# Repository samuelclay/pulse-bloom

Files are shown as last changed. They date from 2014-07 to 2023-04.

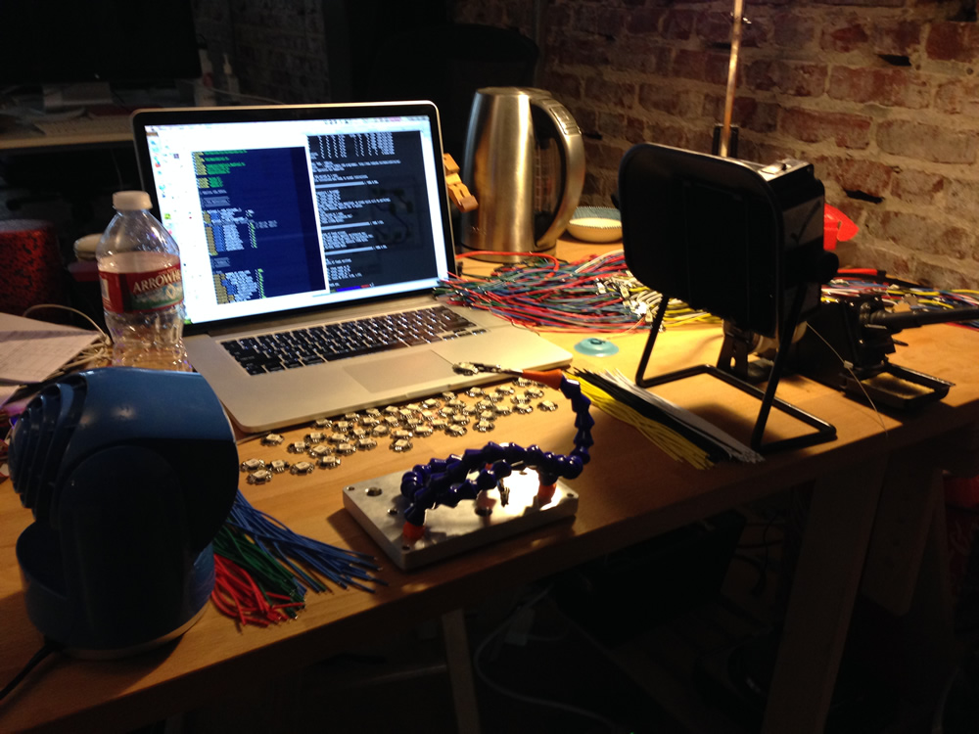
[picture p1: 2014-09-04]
blog/Pulse & Bloom - Soldering leds.jpg

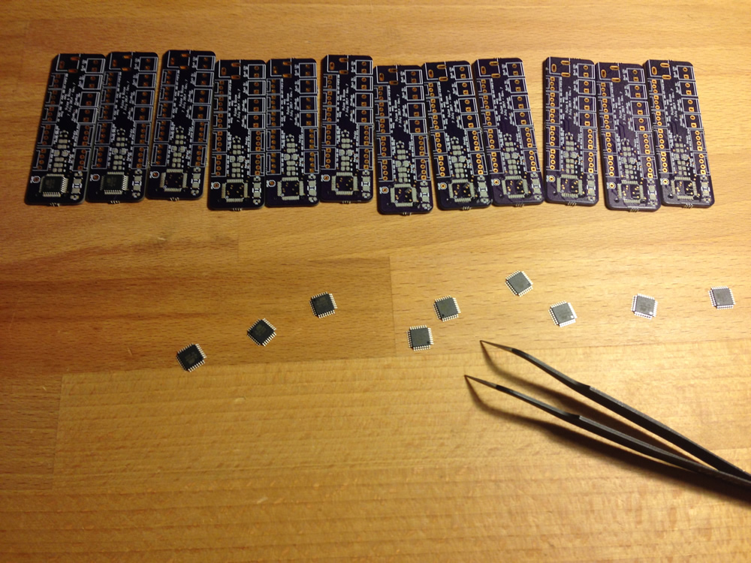
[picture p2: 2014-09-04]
blog/Pulse & Bloom - Soldering boards.jpg

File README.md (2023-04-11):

# Pulse & Bloom

Pulse & Bloom at Night

This was my second year attending Burning Man. Many use Burning Man as a week to detach from their workweek and experience a new life of intense leisure. Not me, I come to Burning Man to build.

Pulse & Bloom is a [2014 honorarium installation](http://www.burningman.com/installations/art_honor.html). The core team of 6 people — [Saba Ghole](https://twitter.com/sabarani), [Shilo Shiv Suleman](https://twitter.com/shilo1221), [Rohan Dixit](https://twitter.com/rd108), [Heather Stewart](https://www.facebook.com/heather.stewart.3388), [Luke Iseman](https://twitter.com/liseman), and [myself](http://twitter.com/samuelclay) — built 20 interactive lotus flowers made out of steel and rowlux. Each lotus flower ranges from 8 to 18 feet tall, each of which lights up with your pulse. You and another person can put your hands on a couple of Hamsa hands at the base of the lotus flower and your respective heartbeats will light up the flower.

We've gotten some great press coverage at [the BBC](http://www.bbc.com/news/in-pictures-29059374), [The Guardian](http://www.theguardian.com/artanddesign/gallery/2014/sep/06/photography-new-york-fashion-gaza-islamic-state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), [The Atlantic's Big Picture](http://www.theatlantic.com/infocus/2014/09/burning-man-2014/100802/#img07) [twice](http://www.theatlantic.com/infocus/2014/09/burning-man-2014/100802/#img22), [CBS News](http://www.cbsnews.com/pictures/burning-man-2014/9/), [NBC News](http://www.nbcnews.com/pop-culture/pop-culture-news/desert-dwellers-burning-man-festival-full-swing-n192541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), and [MSNBC](http://on.msnbc.com/1qkUN4c).

Read the entire writeup at http://www.ofbrooklyn.com/2014/09/6/building-pulse-bloom-biofeedback-burning-man-2014/.

## Setup and installation

Download the AVR GCC toolchain. You can use this homebrew-avr library to install on macOS: https://github.com/osx-cross/homebrew-avr

## Firmware

Here you can find the firmware used to program the main circuit board's ATmega328p chip, as well as designs for the laser cut cowl that sits over the pulse sensor's Si1143x IC. 

The easiest way to read the firmware is to dive into `src/pulse.cpp`. It has all of the pulse and rest states and handles the high level logic.

The state machine that runs the entire routine is determined by a couple of critical measurements. The program takes a measurement of both pulse sensors and determines whether a finger is covering either of them and whether or not that finger has an active pulse going.

    // Modes
    void determinePlayerMode();
    void determineFingerMode(int sensor1On, int sensor2On);
    void resetStem(PulsePlug *pulse);
    uint8_t adjustBpm(PulsePlug *pulse);
    
When there are no fingers on either of the pulse sensors, the program runs the rest state, which is a blue-topped lotus with a small blue snake running up and down the stem. The program is merely waiting for somebody to put their finger on a sensor.

    // State: resting
    void runResting();
    void runRestStem();
    void runRestStem(PulsePlug *pulse, int16_t currentLed);
    void clearStemLeds(PulsePlug *pulse);
    void beginPetalResting();
    bool runPetalResting();

Before a heartbeat is shown an accurate measurement of a heartbeat needs to be read. In order to determine whether a heartbeat is found and at what speed, a number of light detection measurements are taken and analyzed. I simply find the high frequency curve (the heartbeat) and the low frequency curve (the light sensors leveling out) and then use a simple peak and valley hueristic to determine the moment a heartbeat begins. This can take up to two or three seconds at first, so a bit of unwinding animation prepares you when you first put your finger on the sensor.

When a finger is detected, the stem snake lights shoot backwards up and down the lotus in prep for a heartbeat. This looks seamless as it clears the stem. This way a heartbeat doesn't interrupt the rest state.

    // State: end resting
    void beginSplittingStem();
    void runSplittingStem();
    void runSplittingStem(PulsePlug *pulse, int16_t currentLed);

When a heartbeat is detected, it is first shot up the stem. The color is determined by how many pulse sensors are being used. 1 heartbeat shows amber. 2 heartbeats show in white and light red.

    // State: stem rising
    bool runStemRising(PulsePlug *pulse, PulsePlug *shadowPulse);

Once the heartbeat reaches the top of the stem, the petals then fill with light.

    // State: petal rising
    void beginPetalRising();
    bool runPetalRising();

After a set delay, the petal slowly lose light while waiting for the next heartbeat.

    // State: petal falling
    void beginPetalFalling();
    bool runPetalFalling();

Lots of debugging messages have been left in the code and are accessible using the Serial pin on the board. Just turn on `USE_SERIAL`, which is commented out at top. Note that this increases binary code size by about 2.5K. I wrote a lot of logging.

    // Debugging
    void printHeader();
    void blink(int loops, int loopTime, bool half);
    int freeRam ();

## Contact 

I'm happy to [answer any questions on Twitter](https://twitter.com/samuelclay) or [over email](mailto:pulsebloom@ofbrooklyn.com).

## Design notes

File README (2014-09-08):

<style>
#OB-pulse-bloom ol,
#OB-pulse-bloom ul {
    margin-left: 24px;
}
#OB-pulse-bloom li {
    color: inherit;
    font-size: inherit;
    list-style-position: outside;
}
#OB-pulse-bloom ol li {
    list-style-position: outside;
    list-style-type: decimal;
}
#OB-pulse-bloom img {
    margin: 24px auto;
    border: 1px solid #303030;
    display: block;
}
#OB-pulse-bloom img.small {
    float: left;
    margin-right: 24px;
}
#OB-pulse-bloom img.no-border {
    border: none;
}
#OB-pulse-bloom pre code {
    display: block;
    overflow-y: hidden;
}
</style>

<div id="OB-pulse-bloom">

This was my second year attending Burning Man. Many use Burning Man as a week to detach from their workweek and experience a new life of intense leisure. Not me, I come to Burning Man to build.

Pulse & Bloom is a [2014 honorarium installation](http://www.burningman.com/installations/art_honor.html). The core team of 6 people — [Saba Ghole](https://twitter.com/sabarani), [Shilo Shiv Suleman](https://twitter.com/shilo1221), [Rohan Dixit](https://twitter.com/rd108), [Heather Stewart](https://www.facebook.com/heather.stewart.3388), [Luke Iseman](https://twitter.com/liseman), and [myself](http://twitter.com/samuelclay) — built 20 interactive lotus flowers made out of steel and rowlux. Each lotus flower ranges from 8 to 18 feet tall, each of which lights up with your pulse. You and another person can put your hands on a couple of Hamsa hands at the base of the lotus flower and your respective heartbeats will light up the flower.

We've gotten some great press coverage at [the BBC](http://www.bbc.com/news/in-pictures-29059374), [The Guardian](http://www.theguardian.com/artanddesign/gallery/2014/sep/06/photography-new-york-fashion-gaza-islamic-state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), [The Atlantic's Big Picture](http://www.theatlantic.com/infocus/2014/09/burning-man-2014/100802/#img07) [twice](http://www.theatlantic.com/infocus/2014/09/burning-man-2014/100802/#img22), [CBS News](http://www.cbsnews.com/pictures/burning-man-2014/9/), [NBC News](http://www.nbcnews.com/pop-culture/pop-culture-news/desert-dwellers-burning-man-festival-full-swing-n192541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), and [MSNBC](http://on.msnbc.com/1qkUN4c).

As usual, the [complete source code for Pulse & Bloom is on GitHub](https://github.com/samuelclay/pulse-bloom).

### Your heartbeat in light

Here's a video of all twenty lotus flowers in full working order.

<video src="http://static.newsblur.com.s3.amazonaws.com/ofbrooklyn/Pulse%20%26%20Bloom.mp4" autoplay loop muted width="650"></video>

Each lotus flower is blue until a person or two sits down at its base and places their hand on the pulse sensor. You can see the Hamsa hand and its embedded pulse sensor in this shot of my girlfriend Brittany and me working on keeping the electronics going.


<h6 style="margin-top: -24px;text-align: right;">Photo credit Jim Urquhart / Reuters</h6>

When a pulse is read, the lotus flower shoots the heartbeat up the stem and into the petals, where it blooms in a brilliant display of amber. When two people's hands are being measured, both of their heartbeats are shown as two distinct colors.

## How the electronics are made

There are five stages to making the electronics:

 1. [Making the custom circuit boards](#boards)
 2. [Making the custom pulse sensors](#sensors)
 3. [Driving the high current LEDs](#leds)
 4. [Writing the firmware](#firmware)
 5. [Powering the lotuses](#power)

### 1. Making the custom circuit boards

The circuit board controls all of the lighting, sensors, timing, and debugging sequences. A reliable circuit board couldn't just be an Arduino and a breadboard. I decided to use [OSH Park](http://www.oshpark.com) and [OSH Stencils](http://www.oshstencils.com) to fabricate inexpensive circuit boards. I ultimately went through seven revisions while we worked out the final design of the lotuses. This included adding additional lights, additional sensors, controls for EL wire, and better power management using an external buck converter.

This board has support for multiple high current petal LEDs driven by digital RGB pins (used for fading colors in and out using PWM) and in multiple voltages. The high current petal LEDs runs on 12V, which comes directly off the battery, the ATmega328p chip and stem LEDs run at 5V, and the pulse sensor runs at 3.3V.

To convert 12V to 5V I use [a $3 switching voltage regulator from Electrodragon](http://www.electrodragon.com/product/better-than-lm2596-dc-dc-step-down-adjustable-power-supply-module/). This requires a +/- connection for both 12V in and 5V out. To convert 5V to 3.3V I used a linear voltage regulator soldered directly on the board, since the current requirements of the pulse sensor were around 20mA. The heat dissipated was negligible compared to the rest of the circuit.

I also added terminal connections for two 5 meter LEDs that wrapped around the tall lotus stem. We attached two 5 meter LED strips around the stems because when two people put their hands on the two pulse sensors, we need an easy way to show both heartbeats without one winning out over the other. When only one person's hand in being measured, both 5 meter light strips show the same color, which makes it that much brighter for a single person.

Lastly, the two pulse sensors terminate their I2C wires directly on the board. I used two separate I2C channels instead of one to cut down on time. I could easily have put both pulse sensors on the same I2C connections, but that would've required both pull-up resistors on the SDA and SCL data lines as well as a rewrite of the timing functions for the sensor.

All of these terminations are made using 2.5mm and 3.5mm pitch screw terminals. In hindsight I would have used female JST-SM mounted connectors and ordered custom wires with JST-SM male connectors. I assumed the lowest common denomenator would be bare tinned wire, but all of the bare wires could easily have been switched over to polarized, latching connectors. This would have reduced over 90% of the field work I had to perform on boards, as their wire would fall out of the screw terminals due to not being screwed in with enough force.



The board was laid out to be as big as a pack of gum. All of the 12V traces are thickened and isolated on the right side of the board. They are rated for 3 amps although they would end up only driving 1 amp on the playa.



These boards are then stenciled with solder paste and populated with their chips and passive components.



An inexpensive hot plate is used to reflow the solder. The chip is in a TQFP package, which has a 0.5mm pitch between pins. This makes it nearly impossible to hand solder. This stencil and reflow technique works well and my yield stayed high at around 95%.



Finally, the board is ready to be populated with screw terminals.



The final board in a dust-proof enclosure.



### 2. Making the custom pulse sensors

This was both the riskiest piece of the puzzle and also the most fun to build. In order to show your heartbeat on the lotus, I need to have a clear reading of your pulse. There are a fair number of issues with most off-the-shelf heartbeat sensors, including:

 * **Cost**: While a $50 pulse sensor is nice, it's way out of our budget. We spent $6 in components to make each of our pulse sensors for a total of 40 sensors (two per lotus).
 * **Design affordance**: There were a fair number of pulse sensors that required an infrared light on one side of your finger and an infrared detector/receiver on the other. This clamping of your finger wasn't something we could get away with in the desert. We needed a sensor you could just touch and hold on one side. It needed to be a simple interface so we wouldn't have to show any instructions.
 * **Reliability**: When a sensor gets covered in dust, will it still work? Infrared light, thankfully, passes through a layer of dust and can read the changes in blood flow in your finger. Some options were entirely visual and they would have performed quite poorly out on the playa.

The first prototype I built suffered from the design affordance and reliability issues, although it worked pretty well in ideal conditions.

<video src="http://static.newsblur.com.s3.amazonaws.com/ofbrooklyn/Pulse%20%26%20Bloom%20-%20Sensor%20opamp.mp4" autoplay loop muted width="650"></video>

We ended up finding an IC by Silicon Labs called the Si1143x, which uses three LEDs — two infrared and one visible — and a small QFN-10 sized light sensor.



I built out a small PCB the size of a fingertip.



This tiny IC is a bit tricky to solder as it has no leads and the pins are extremely close together. My yield dropped to about 80%, but 4 out of every 5 pulse sensors I built worked perfectly the first time. If they failed, I would remount them on the hot plate and try wicking away any solder bridges I could find. This worked only about half the time. After that I gave up and now have a plastic cup full of broken pulse sensors.



Finally the sensor is hooked up and a tiny red light is emitted, letting people know where to put their fingers.



### 3. Driving the high current LEDs

What turned these lotuses from flowers into gems are the high current LEDs mounted in the petals at the top. There are 9 of these high current LEDs per lotus, split into groups of three, each driven by a constant current driver. 

If you were to look at one of these LEDs from a few feet away, you would immediately see spots in your eyes. They are extremely bright pinpoints of light. The fact that they are also full color and need a heatsink due to their brightness means that you won't just find these in an easy package ready for plugging in.


<h6 style="margin-top: -24px;text-align: right;">Photo credit Jim Urquhart / Reuters</h6>

Normally a single LED is powered by a single constant current driver. This driver can drive up to 1A of current at 12V. Because we were only using a single channel of color (blue) in the rest state, which is where the lotus spent most of its time, we could triple the number of LEDs driven by a single constant current driver. 

When in use the petals glow amber, which uses two channels (100% red, 50% green) but only for a moment while at peak current. So while the peak current is above what this constant current driver is rated for, it's only at peak and therefore within our tolerance.

Using a Chinese distributor, we bought these Sparkfun high current LEDs for $0.86 each instead of the full $15. However, we also bought 80 of Sparkfun's PicoBucks to use as our constant current driver. While we could have built this ourselves to save money, buying 80 of something at $15 each is still only $1.2k, while building them ourselves would only have saved a few hundred dollars.




We bought 200 high current LEDs, all of which had to have their 6 anode and cathode connections soldered.



In order to connect 9 high current LEDs to the board, we need to drive them in groups of three. Each group has 6 connections: red, green, blue anodes, and red, green, blue cathodes. The wiring diagram for this setup can get a bit rats nesty, but the end result was fairly easy to work with, as the picobuck groups didn't cross.



Finally, a shot of a complete picobuck with the wire connectors in the background.



### 4. Writing the firmware

The [complete source code for Pulse & Bloom is on GitHub](https://github.com/samuelclay/pulse-bloom). There you can find the firmware used to program the main circuit board's ATmega328p chip, as well as designs for the laser cut cowl that sits over the pulse sensor's Si1143x IC. 

The easiest way to read the firmware is to dive into `src/pulse.cpp`. It has all of the pulse and rest states and handles the high level logic.

The state machine that runs the entire routine is determined by a couple of critical measurements. The program takes a measurement of both pulse sensors and determines whether a finger is covering either of them and whether or not that finger has an active pulse going.

    // Modes
    void determinePlayerMode();
    void determineFingerMode(int sensor1On, int sensor2On);
    void resetStem(PulsePlug *pulse);
    uint8_t adjustBpm(PulsePlug *pulse);
    
When there are no fingers on either of the pulse sensors, the program runs the rest state, which is a blue-topped lotus with a small blue snake running up and down the stem. The program is merely waiting for somebody to put their finger on a sensor.

    // State: resting
    void runResting();
    void runRestStem();
    void runRestStem(PulsePlug *pulse, int16_t currentLed);
    void clearStemLeds(PulsePlug *pulse);
    void beginPetalResting();
    bool runPetalResting();

Before a heartbeat is shown an accurate measurement of a heartbeat needs to be read. In order to determine whether a heartbeat is found and at what speed, a number of light detection measurements are taken and analyzed. I simply find the high frequency curve (the heartbeat) and the low frequency curve (the light sensors leveling out) and then use a simple peak and valley hueristic to determine the moment a heartbeat begins. This can take up to two or three seconds at first, so a bit of unwinding animation prepares you when you first put your finger on the sensor.

When a finger is detected, the stem snake lights shoot backwards up and down the lotus in prep for a heartbeat. This looks seamless as it clears the stem. This way a heartbeat doesn't interrupt the rest state.

    // State: end resting
    void beginSplittingStem();
    void runSplittingStem();
    void runSplittingStem(PulsePlug *pulse, int16_t currentLed);

When a heartbeat is detected, it is first shot up the stem. The color is determined by how many pulse sensors are being used. 1 heartbeat shows amber. 2 heartbeats show in white and light red.

    // State: stem rising
    bool runStemRising(PulsePlug *pulse, PulsePlug *shadowPulse);

Once the heartbeat reaches the top of the stem, the petals then fill with light.

    // State: petal rising
    void beginPetalRising();
    bool runPetalRising();

After a set delay, the petal slowly lose light while waiting for the next heartbeat.

    // State: petal falling
    void beginPetalFalling();
    bool runPetalFalling();

Lots of debugging messages have been left in the code and are accessible using the Serial pin on the board. Just turn on `USE_SERIAL`, which is commented out at top. Note that this increases binary code size by about 2.5K. I wrote a lot of logging.

    // Debugging
    void printHeader();
    void blink(int loops, int loopTime, bool half);
    int freeRam ();

### 5. Powering the lotuses

While much of what I built above came out of knowledge I already had, learning how to power this large of an installation off just a battery was all new to me. I'm used to microelectronics that run off a coin cell or AA batteries.

#### Measuring current and power usage

First, in order to figure out how big of a battery we needed, we had to measure how much power we were taking. I hooked up an ammeter in series with a single lotus to measure the current draw. In rest state, a single lotus drew 0.75A at 12V. In the active pulsing heartbeat state, a single lotus drew 1.5A at 12V. Since a lotus spends 95% of its time at rest, we rounded the average current consumption to 1A.

Twenty lotuses at 1A at 12V meant we needed 240Ah to sustain a 12 hour night. A car battery was recommended, but car batteries can only discharge down to 80% without irreparable harm. However, a marine deep-cycle battery can go down to 20% without harm. 



This 150 lb. battery has enough capacity, although we ended up adding a couple 6V batteries in series (to boost them to 12V) and then running them in parallel to offset some of the load.

#### Dealing with the voltage drop

A big issue we ran into was the voltage drop across the power lines. We placed the batteries on the edge of the installation, which meant some of the lotuses had 20 meters of wire between them and the battery. The voltage drop per 10 meter section is nearly 2V, which means that the voltage reaching the further lotuses was down to 7.5V. 

The high current LEDs were not able to be smoothly driven at this low of a voltage, causing them to flicker. We determined that a voltage drop was responsible for the flickering, which got worse the further the lotus sat from the batteries. But when we discovered this the wires had already been trenched 6 inches beneath the playa. A day of work lost, but we sucked it up and ripped out all of the ground wiring to accommodate the battery which had to be moved into the center of the installation.

At the end of each night we had to bike out with a trike and carry all 300 lbs. of batteries back to camp, where they were hooked up to a 1 kW solar array, where they were charged at 48A over 6 hours.

## Prototyping the lotuses

Back at American Steel in Oakland, the lotus stems, bases, and petals were ready to be hooked up. These twenty lotus stems were bent by Heather. They range from 6ft to 16ft in length and each weighs 50 lbs.



Such a heavy stem needs a larger base and heavy anchors to stay upright in the wind.



We placed the lily pad over the base to cover it up and then added all of the electronics. Lights, sensors, and circuit boards all had to be mounted.

This is a photo of our first complete lotus flower. Just compare its sheer size to Shilo.



Once we were confident that one lotus would successfully light we left the other 19 lotuses packed away for assembly on the playa.

## A dusty scene

We drove out in the biggest rental car I could get my hands on. Our minivan is full of electronics, bicycles, tents, costumes, coolers full of fruit and veggies, dry snacks, and water.



Since we were early arrival, they give you these red bracelets. They say *Work hard, don't do stupid shit*.



The boards would accumulate dust on them everyday. Our plastic enclosures turned out to be too big for the holes we made in the platform. So we ended up using ziploc bags. These baggies stayed attached, but the only reason they didn't cause any issues is that the boards worked just fine in the dust, as you can see here. 

If dust was a real problem for the boards, then I would have spent a whole lot more time making a tight fitting enclosure and a hole for it that protects it both from the elements and from people.



The playa gets covered in dust storms regularly throughout the week. A particularly nasty dust storm is pictured here, eating our poor lotus flowers alive.



Although during the day when its not dust storming the lotuses offer a cozy respite from the heat of the playa. 


<h6 style="margin-top: -24px;text-align: right;">Photo credit Jim Urquhart / Reuters</h6>

The entire process lasted 4 months with 2.5 months of nearly full-time work on my part. I'm thrilled that I get to open-source both the process and the firmware. I hope others who build art installations can use some of my lessons learned here. I'm happy to [answer any questions on Twitter](https://twitter.com/samuelclay).

See you next year on the playa!

</div>

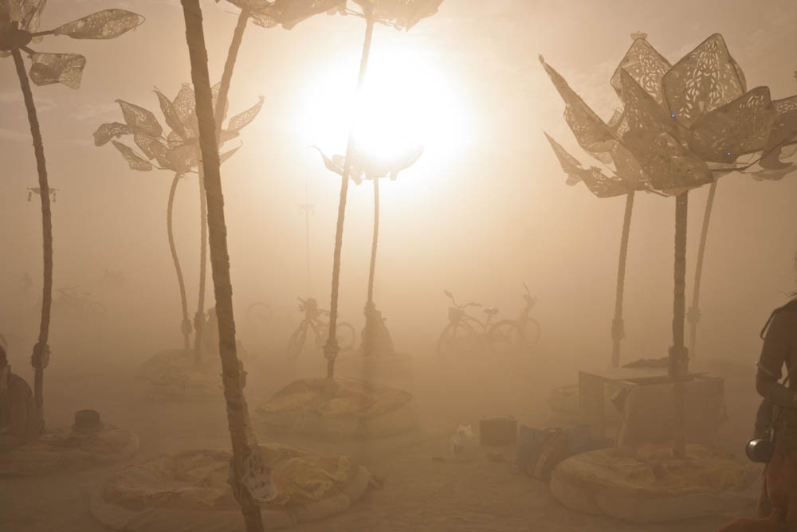
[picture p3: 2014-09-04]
blog/Pulse & Bloom - Dust.jpg

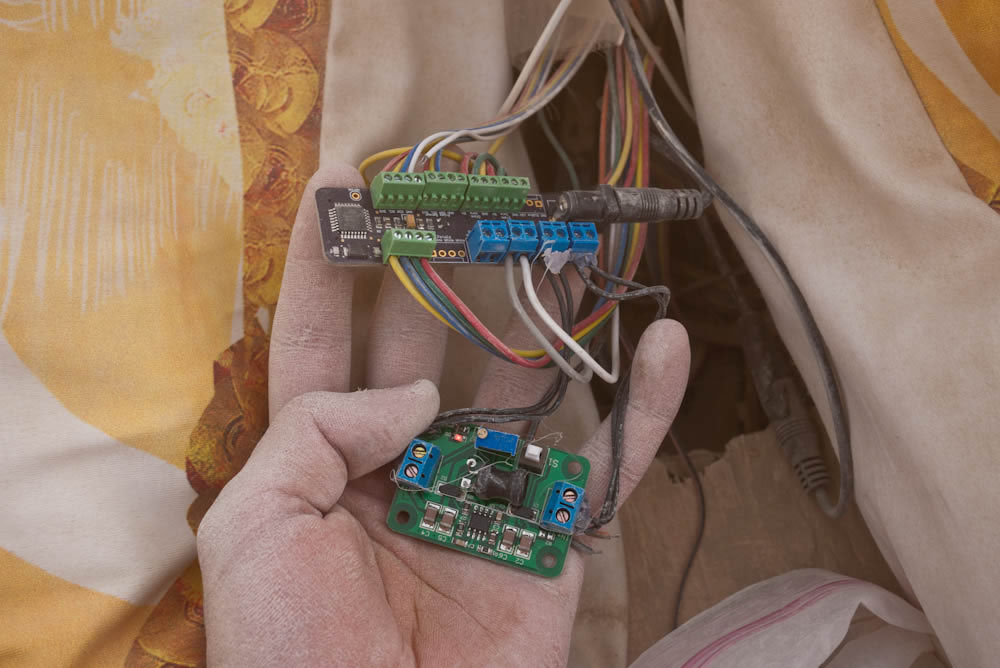
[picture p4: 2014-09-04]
blog/Pulse & Bloom - Dusty Board.jpg

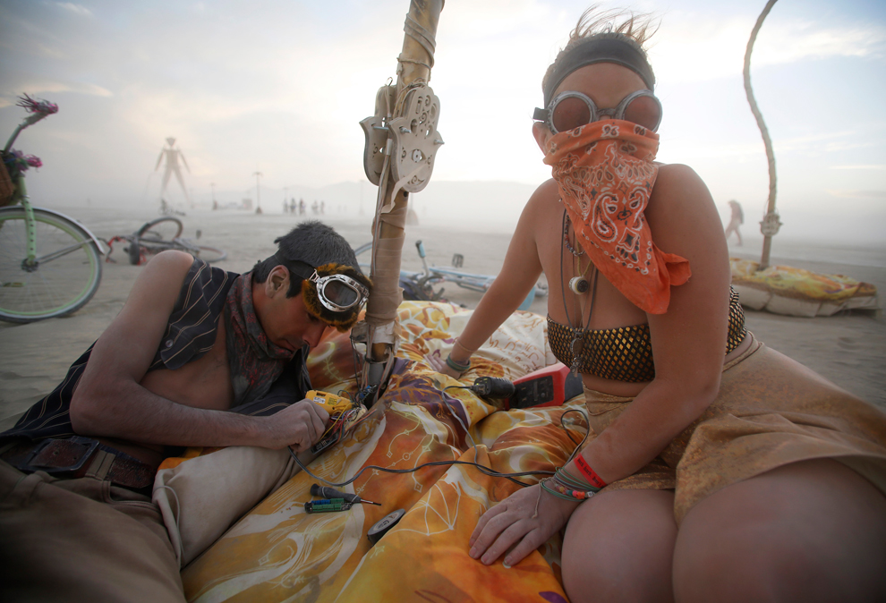
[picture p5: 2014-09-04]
blog/Pulse & Bloom - Glue Gun.jpg

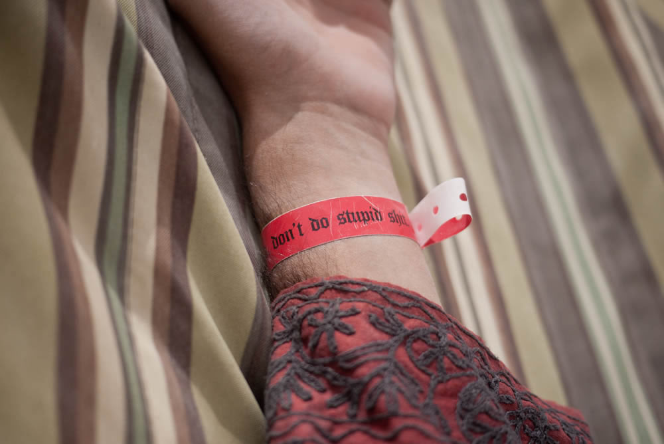
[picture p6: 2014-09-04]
blog/Pulse & Bloom - Bracelet.jpg

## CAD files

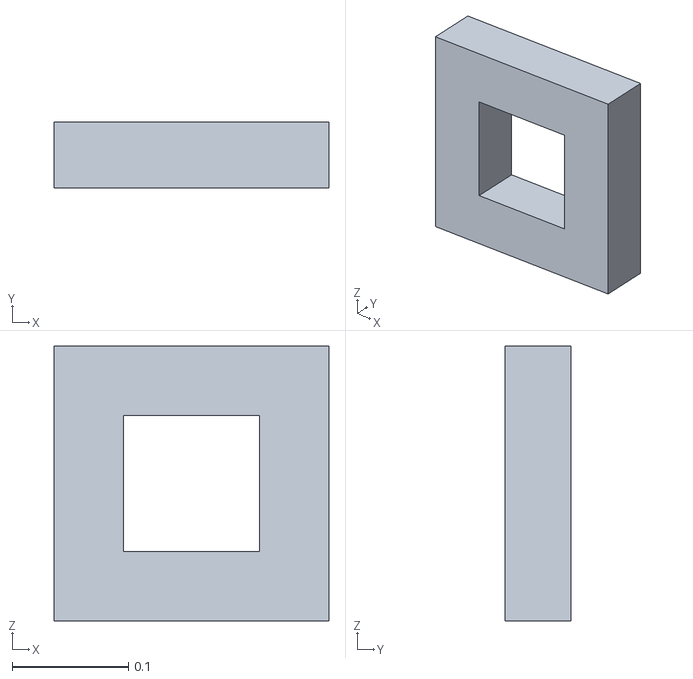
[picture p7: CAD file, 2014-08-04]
cowl/Pulse Sensor Cowl.obj
0.237 x 0.057 x 0.237

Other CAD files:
cowl/Pulse Sensor Cowl.skp
cowl/Pulse Sensor Cowl~.skp

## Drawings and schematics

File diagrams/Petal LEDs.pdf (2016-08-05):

## Petal LEDs.graffle

## Board

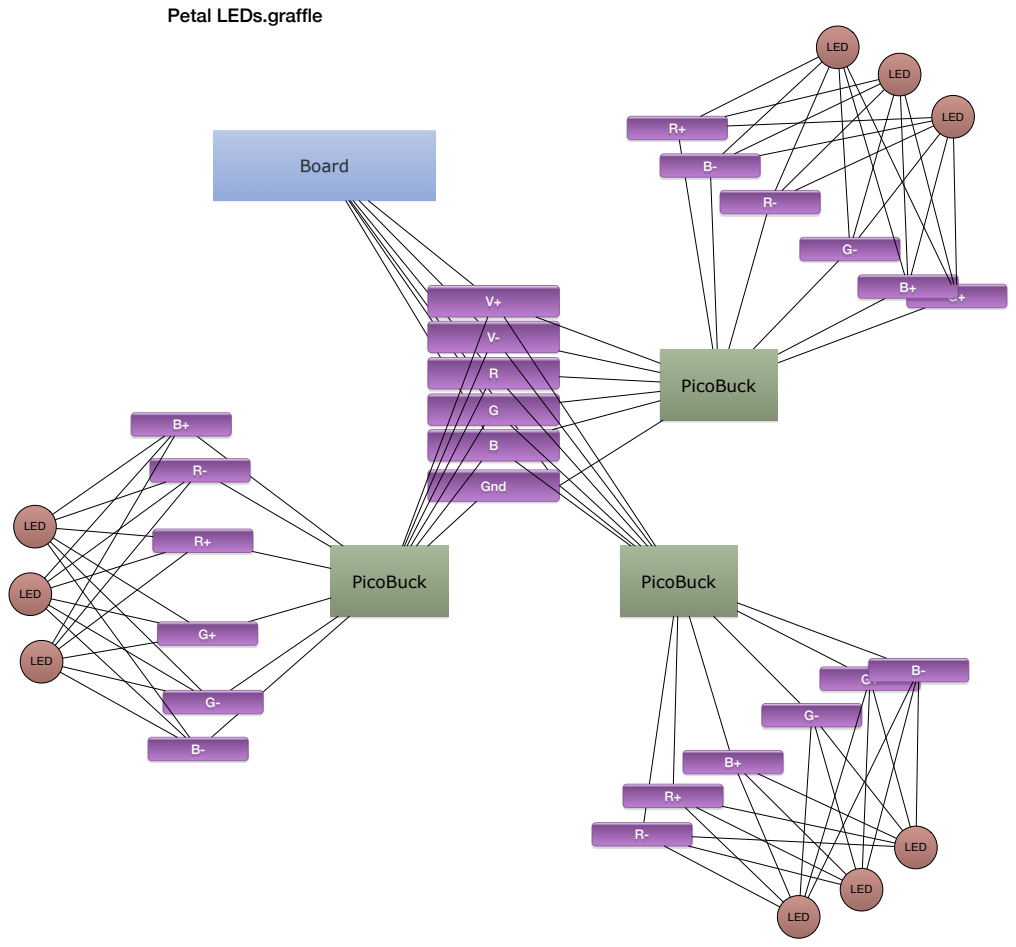
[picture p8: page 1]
LED; Gnd; PicoBuck

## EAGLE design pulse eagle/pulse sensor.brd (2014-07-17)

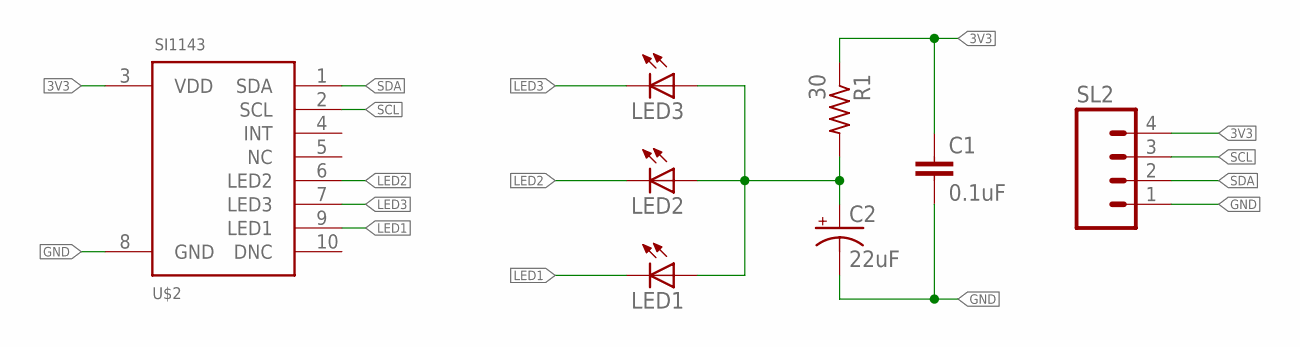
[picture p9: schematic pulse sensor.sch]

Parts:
C1: 0.1uF; 0402-CAP
C2: 22uF; EIA3216
LED1, LED2, LED3: LED1206; LED-1206
R1: 30; R0402
SL2: M04SMD; 1X04-SMD
U$2: SI1143

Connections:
3V3: C1.1, R1.1, SL2.4, U$2.3 (VDD)
GND: C1.2, C2.C (-), SL2.1, U$2.8 (GND)
LED1: LED1.C, U$2.9 (LED1)
LED2: LED2.C, U$2.6 (LED2)
LED3: LED3.C, U$2.7 (LED3)
unnamed: C2.A (+), LED1.A, LED2.A, LED3.A, R1.2
SCL: SL2.3, U$2.2 (SCL)
SDA: SL2.2, U$2.1 (SDA)

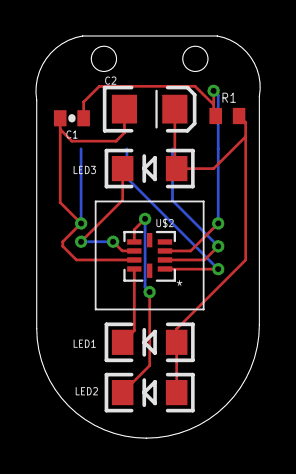
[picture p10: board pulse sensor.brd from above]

Board: 2 copper layers, 12.5 x 22.3 mm, 8 parts (1 on the bottom side), 8 nets.

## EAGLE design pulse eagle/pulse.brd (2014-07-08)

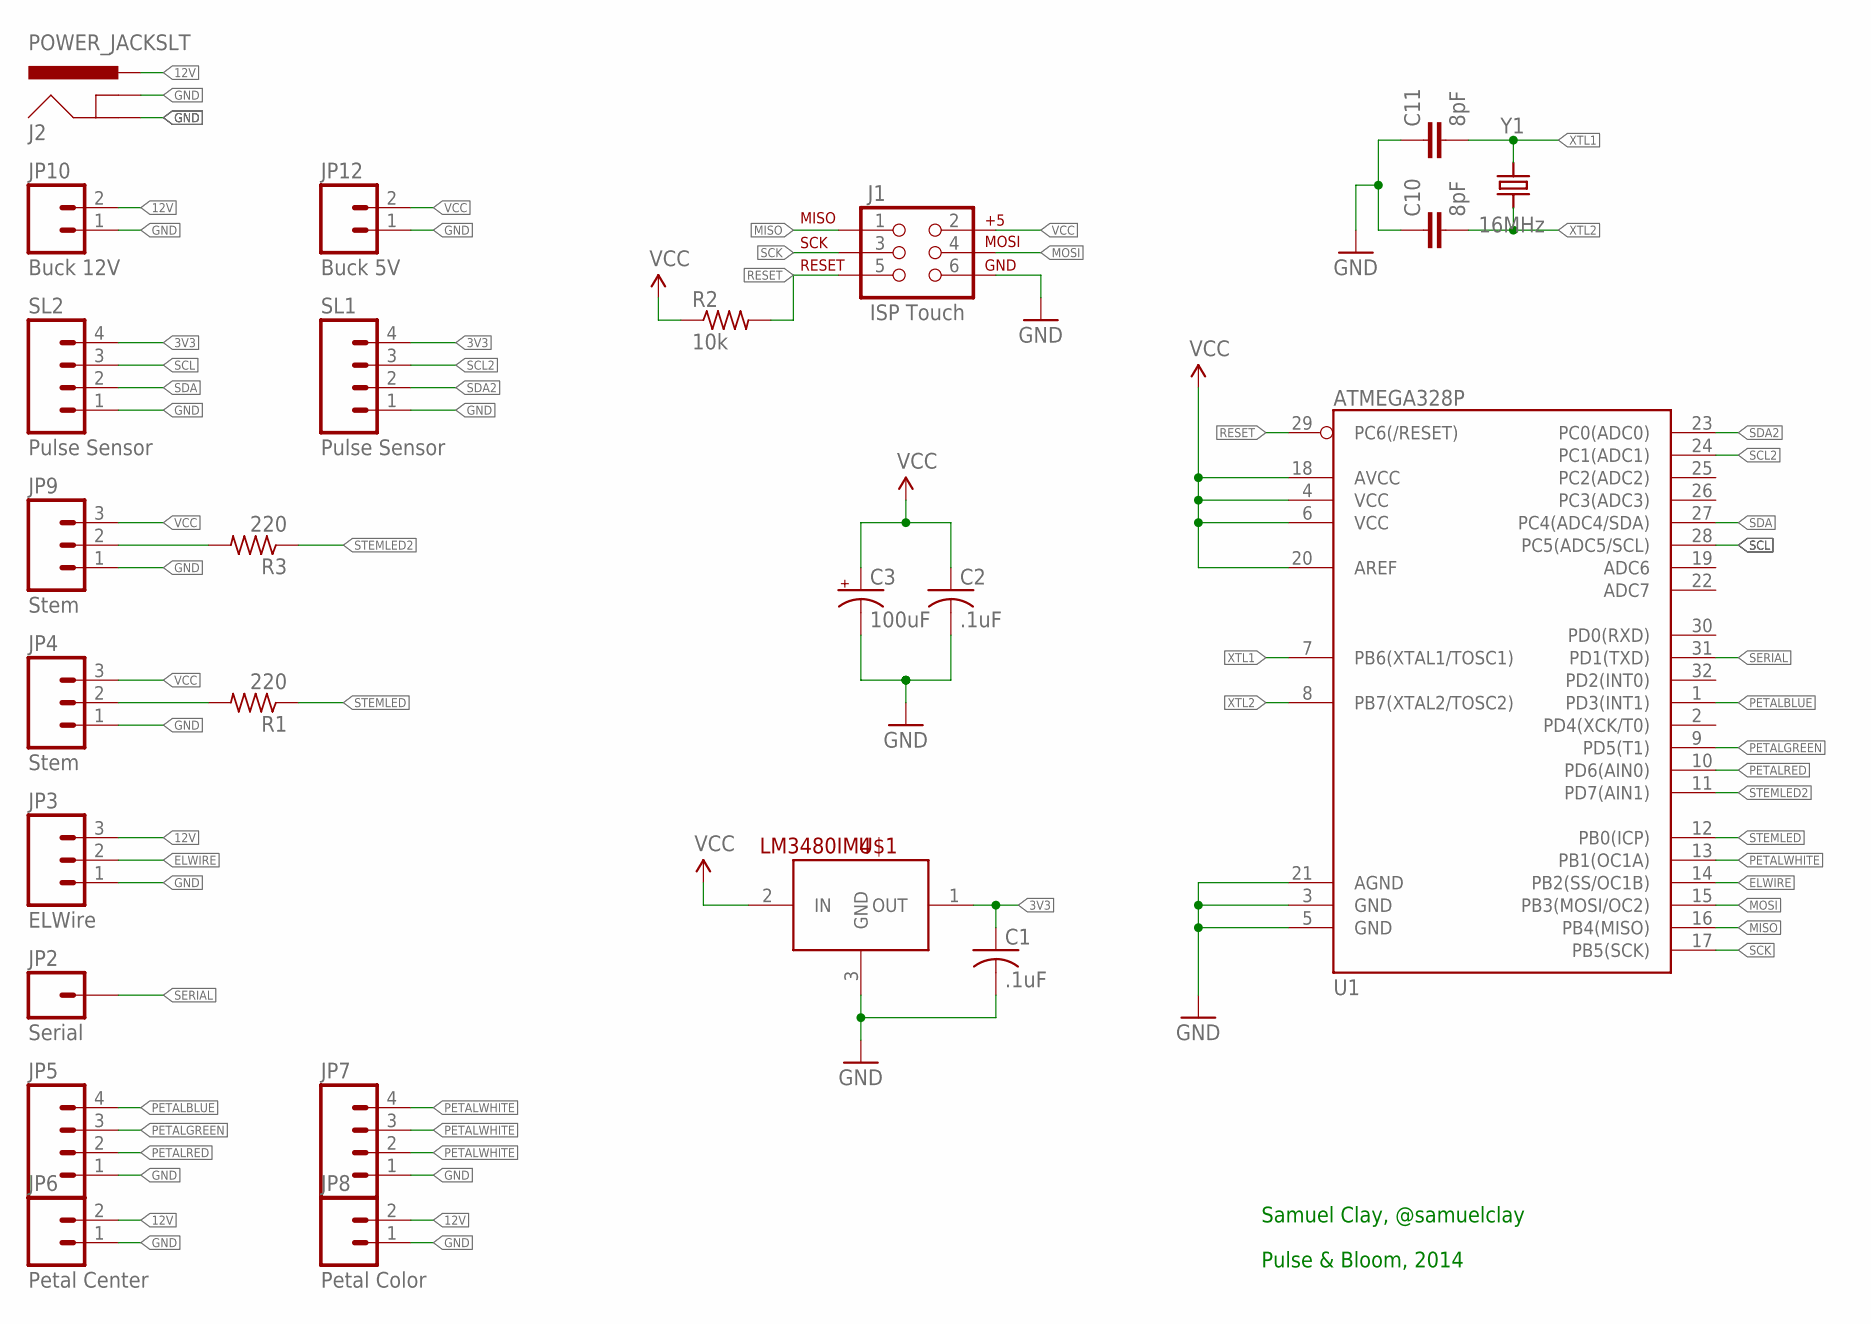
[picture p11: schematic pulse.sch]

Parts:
C1, C2: .1uF; C0805
C3: 100uF; EIA3216
C10, C11: 8pF; 0805
J1: ISP Touch; AVX_9188_6-WAY_MATING_GUIDE
J2: POWER_JACKSLT; POWER_JACK_SLOT
JP2: Serial; 1X01
JP3: ELWire; MOLEX-1X3_LOCK
JP4, JP9: Stem; MOLEX-1X3_LOCK
JP5: M04POLAR_LOCK; MOLEX-1X4_LOCK
JP6: Petal Center; SCREWTERMINAL-3.5MM-2_LOCK
JP7: M04POLAR; MOLEX-1X4
JP8: Petal Color; SCREWTERMINAL-3.5MM-2_LOCK
JP10: Buck 12V; SCREWTERMINAL-3.5MM-2_LOCK
JP12: Buck 5V; SCREWTERMINAL-3.5MM-2_LOCK
R1, R3: 220; R0805
R2: 10k; R0805
SL1, SL2: Pulse Sensor; MOLEX-1X4_LOCK
U1: ATMEGA328P; TQFP32-08
U$1: LM3480IM4; SOT23-3
Y1: 16MHz; NX5032GA

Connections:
3V3: C1.1, SL1.4, SL2.4, U$1.1 (OUT)
12V: J2.PWR, JP3.3, JP6.2, JP8.2, JP10.2
ELWIRE: JP3.2, U1.14 (PB2(SS/OC1B))
GND: C1.2, C2.2, C3.C (-), C10.1, C11.1, J1.6, J2.GND@1 (GNDBREAK), J2.GND@2 (GND), JP3.1, JP4.1, JP5.1, JP6.1, JP7.1, JP8.1, JP9.1, JP10.1, JP12.1, SL1.1, SL2.1, U1.3 (GND), U1.5 (GND), U1.21 (AGND), U$1.3 (GND)
MISO: J1.1, U1.16 (PB4(MISO))
MOSI: J1.4, U1.15 (PB3(MOSI/OC2))
unnamed: JP9.2, R3.2
unnamed: JP4.2, R1.2
PETALBLUE: JP5.4, U1.1 (PD3(INT1))
PETALGREEN: JP5.3, U1.9 (PD5(T1))
PETALRED: JP5.2, U1.10 (PD6(AIN0))
PETALWHITE: JP7.2, JP7.3, JP7.4, U1.13 (PB1(OC1A))
RESET: J1.5, R2.2, U1.29 (PC6(/RESET))
SCK: J1.3, U1.17 (PB5(SCK))
SCL: SL2.3, U1.28 (PC5(ADC5/SCL))
SCL2: SL1.3, U1.24 (PC1(ADC1))
SDA: SL2.2, U1.27 (PC4(ADC4/SDA))
SDA2: SL1.2, U1.23 (PC0(ADC0))
SERIAL: JP2.1, U1.31 (PD1(TXD))
STEMLED: R1.1, U1.12 (PB0(ICP))
STEMLED2: R3.1, U1.11 (PD7(AIN1))
VCC: C2.1, C3.A (+), J1.2, JP4.3, JP9.3, JP12.2, R2.1, U1.4 (VCC), U1.6 (VCC), U1.18 (AVCC), U1.20 (AREF), U$1.2 (IN)
XTL1: C11.2, U1.7 (PB6(XTAL1/TOSC1)), Y1.P$2 (2)
XTL2: C10.2, U1.8 (PB7(XTAL2/TOSC2)), Y1.P$1 (1)

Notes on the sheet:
Samuel Clay, @samuelclay
Pulse & Bloom, 2014

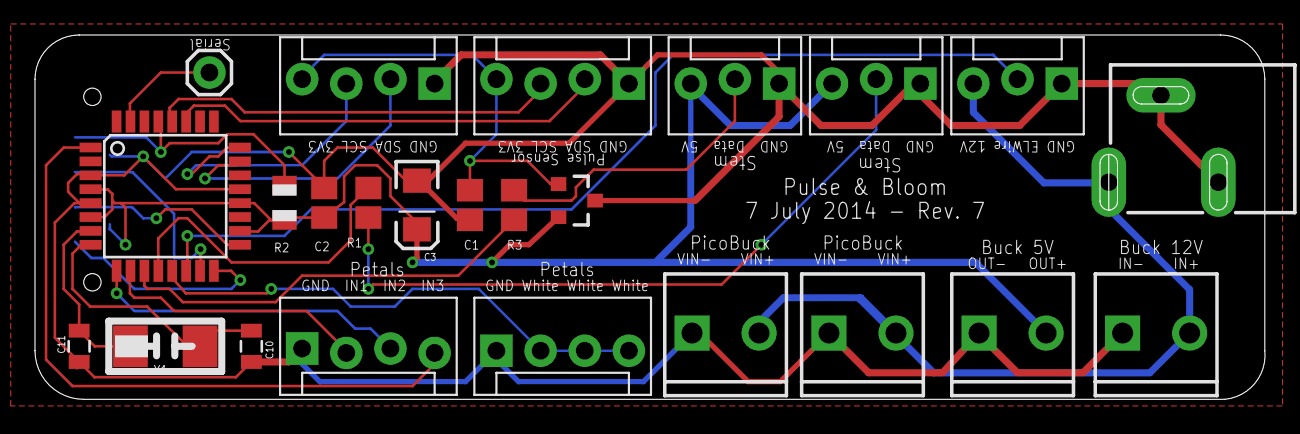
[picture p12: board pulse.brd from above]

Board: 2 copper layers, 70.8 x 21.0 mm, 25 parts (1 on the bottom side), 24 nets.

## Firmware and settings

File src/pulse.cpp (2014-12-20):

// Pulse & Bloom - Pulse Sensor and Lighting
// 2014 - Samuel Clay, samuel@ofbrooklyn.com

#include <avr/io.h>
#include <util/delay.h>     /* for _delay_ms() */
#include <stdio.h>
#include <string.h>
#include <inttypes.h>
#include <wdt.h>
#include <WString.h>
#if defined (__AVR_ATtiny84__)
#include <tiny/wiring.h>
#include <SoftwareSerial/SoftwareSerial.h>
#else
#include <HardwareSerial.h>
#endif
#include <neopixel/Adafruit_NeoPixel.h>
#include <si1143/si1143.h>
#include <QuadraticEase.h>

#include "pulse.h"
#include "sensor.h"
#include "smooth.h"

// #define USE_SERIAL

// ===================
// = Pin Definitions =
// ===================

#if defined (__AVR_ATtiny84__)
const uint8_t stemLedPin          = PB2;
const uint8_t serialPin           = 7;
#elif defined (__AVR_ATmega328P__)
// See si1143.h:digiPin for sensor pins
const uint8_t sensorAPin          = 0;  // SCL=18, SDA=19
const uint8_t sensorBPin          = 14; // SCL=A0, SDA=A1
const uint8_t stemALedPin         = 8;
const uint8_t stemBLedPin         = 7;
const uint8_t petalRedPin         = 3;
const uint8_t petalGreenPin       = 6;
const uint8_t petalBluePin        = 5;
const uint8_t petalWhitePin       = 9;
#endif

// ===========
// = Globals =
// ===========

// Stem
const int NUMBER_OF_STEM_LEDS     = 300;
const int REST_PULSE_WIDTH        = 8;
const int8_t STEMA_PULSE_WIDTH    = 16;
const int8_t STEMB_PULSE_WIDTH    = 16;
volatile int16_t stripACurrentLed = 0;
volatile int16_t stripBCurrentLed = 0;
volatile int16_t splitPivotPoint  = 0;
unsigned long beginSplitTime      = 0;
unsigned long endSplitTime        = 0;
const int STEM_SPLIT_MS           = 800;
const double STEM_DURATION_PCT    = 0.65;

QuadraticEase splitEase;

// Petals
unsigned long beginLedRiseTime    = 0;
unsigned long endLedRiseTime      = 0;
unsigned long beginLedFallTime    = 0;
unsigned long endLedFallTime      = 0;
unsigned long beginLedRestTime    = 0;
unsigned long endLedRestTime      = 0;
uint8_t ledBrightness             = 0;
uint8_t lastBpm                   = 75;
const int16_t PETAL_DECAY_MS      = 850;
const int16_t PETAL_DELAY_MS      = 60;

// Pulses
unsigned long lastPulseATime      = 0;
unsigned long lastPulseBTime      = 0;
unsigned long nextPulseATime      = 0;
unsigned long nextPulseBTime      = 0;
unsigned int bpmPulseA            = lastBpm;
unsigned int bpmPulseB            = lastBpm;
unsigned long lastSensorActiveA   = 0;
unsigned long lastSensorActiveB   = 0;
unsigned long lastFingerSeenA     = 0;
unsigned long lastFingerSeenB     = 0;
const int SENSOR_DECAY_MS         = 60000;
const int FINGERLESS_DECAY_MS     = 1500;
const double SHOW_HEARTBEAT_PCT   = 0.35;

// Pulse sensor
PortI2C myBus(sensorAPin);
PulsePlug pulseA(myBus); 
PortI2C myBus2(sensorBPin);
PulsePlug pulseB(myBus2); 

// States
typedef enum
{
    STATE_RESTING       = 0,
    STATE_AWAKE         = 1,
    STATE_STEM_RISING   = 2,
    STATE_STEM_FALLING  = 3,
    STATE_PETAL_RISING  = 4,
    STATE_PETAL_FALLING = 5,
    STATE_PETAL_LANDING = 6
} state_app_t;
state_app_t app1State;
state_app_t app2State;
state_app_t restState;
state_app_t petalState;

typedef enum
{
    MODE_NONE     = 0,
    MODE_SINGLE_A = 1,
    MODE_SINGLE_B = 2,
    MODE_DOUBLE   = 3
} player_mode_t;
player_mode_t playerMode;
player_mode_t fingerMode;

// Serial
#if defined (__AVR_ATtiny84__)
SoftwareSerial Serial(0, serialPin); // RX, TX
#endif

// Debugging
long debuggingTimer   = 0;
long debuggingSeconds = 0;

// ========
// = Init =
// ========

void setup(){
    analogReference(EXTERNAL);
    pinMode(petalRedPin, OUTPUT);
    pinMode(petalGreenPin, OUTPUT);
    pinMode(petalBluePin, OUTPUT);
    pinMode(petalWhitePin, OUTPUT);
    
    analogWrite(petalRedPin, 0);
    analogWrite(petalGreenPin, 0);
    analogWrite(petalBluePin, 0);
    analogWrite(petalWhitePin, 0);
    
    app1State  = STATE_RESTING;
    app2State  = STATE_RESTING;
    petalState = STATE_RESTING;
    restState  = STATE_RESTING;
    playerMode = MODE_NONE;
    fingerMode = MODE_NONE;
    
    delay(50);
#ifdef USE_SERIAL
    Serial.begin(115200);
    Serial.flush();
    
    Serial.print(F(" ---> Free RAM: "));
    Serial.println(freeRam());
#endif
    printHeader();
    
    pinMode(stemALedPin, OUTPUT);
    digitalWrite(stemALedPin, LOW);
    pinMode(stemBLedPin, OUTPUT);
    digitalWrite(stemBLedPin, LOW);
    clearStemLeds(&pulseA);
    clearStemLeds(&pulseB);
    pulseA.role = ROLE_PRIMARY;
    pulseB.role = ROLE_SECONDARY;
    setupPulseSensor(&pulseA);
    setupPulseSensor(&pulseB);

    for (int i=0; i < 255; i++) {
        analogWrite(petalRedPin, i);
        delay(1);
    }
    for (int i=255; i > 0; i--) {
        analogWrite(petalRedPin, i);
        delay(1);
    }
    for (int i=0; i < 255; i++) {
        analogWrite(petalGreenPin, i);
        delay(1);
    }
    for (int i=255; i > 0; i--) {
        analogWrite(petalGreenPin, i);
        delay(1);
    }
    for (int i=0; i < 255; i++) {
        analogWrite(petalBluePin, i);
        delay(1);
    }
    for (int i=255; i > 0; i--) {
        analogWrite(petalBluePin, i);
        delay(1);
    }


    analogWrite(petalRedPin, 0);
    analogWrite(petalGreenPin, 0);
    analogWrite(petalBluePin, 255);
    analogWrite(petalWhitePin, 0);
    
    // blink(3, 25, true);
}

void loop() {
    bool heartbeat1 = lastPulseATime && nextPulseATime < millis();
    bool heartbeat2 = lastPulseBTime && nextPulseBTime < millis();
    int sensor1On = readPulseSensor(&pulseA);
    int sensor2On = readPulseSensor(&pulseB);
    PulsePlug *pulse1 = &pulseA;
    PulsePlug *pulse2 = &pulseB;
    
#ifdef USE_SERIAL
    if (true && (heartbeat1 || heartbeat2 || 
                 sensor1On >= 0 || sensor2On >= 0 || 
                 app1State || app2State)) {
        Serial.print(F(" ---> ["));
        Serial.print(millis());
        Serial.print(F("] mode: "));        Serial.print(playerMode);
        Serial.print(F(" heartbeat: "));    Serial.print(heartbeat1);
        Serial.print(F("/"));               Serial.print(heartbeat2);
        Serial.print(F(" sensorOn: "));     Serial.print(sensor1On);
        Serial.print(F("/"));               Serial.print(sensor2On);
        Serial.print(F(" appState: "));     Serial.print(app1State);
        Serial.print(F("/"));               Serial.print(app2State);
        Serial.print(F(" restState: "));    Serial.print(restState);
        Serial.print(F("/"));               Serial.print(app2State);
        Serial.print(F(" petalState: "));   Serial.print(petalState);
        Serial.println();
    }
#endif    
    
    // Found fingers, now in transitory state, just skip everything until done
    if (restState == STATE_STEM_RISING) {
        runSplittingStem();
        return;
    }
    if (playerMode == MODE_NONE) {
        lastPulseATime = 0;
        lastPulseBTime = 0;
        nextPulseATime = 0;
        nextPulseBTime = 0;
        app1State = STATE_RESTING;
        app2State = STATE_RESTING;
        if (fingerMode == MODE_NONE) {
            runResting();
            if (petalState != STATE_RESTING) {
                petalState = STATE_PETAL_LANDING;
            }
        }
    }
    
    // Check for real heartbeat, adjust fake heartbeat
    if (sensor1On > 0) {
        bpmPulseA = adjustBpm(pulse1);
        float progress = 1.0;
        if (lastPulseATime) {
            progress = ((float)(millis()-lastPulseATime))/
                       ((float)(nextPulseATime-lastPulseATime));
        }
        lastSensorActiveA = millis();
        if (progress > SHOW_HEARTBEAT_PCT) {
            // If half-way to next heartbeat, immediately show heartbeat
            heartbeat1 = true;
        } else {
            // If not half-way to next heartbeat, push out next heartbeat to align
            // with this real heartbeat.
            Serial.print(" ---> Saw heartbeatA, delaying: ");
            Serial.println(progress);

            nextPulseATime = millis() + 60000.0/bpmPulseA;
        }
    }
    if (sensor2On > 0) {
        float progress = 1.0;
        if (lastPulseBTime) {
            progress = ((float)(millis()-lastPulseBTime))/((float)(nextPulseBTime-lastPulseBTime));
        }
        lastSensorActiveB = millis();
#ifdef USE_SERIAL
        Serial.print(" ---> Progress: ");
        Serial.print(progress);
        Serial.print(" lastbpm: ");
        Serial.print(lastBpm);
        Serial.print(" bpm: ");
        Serial.print(pulse2->latestBpm);
        Serial.print(" newbpm: ");
        Serial.println(adjustBpm(pulse2));
#endif
        bpmPulseB = adjustBpm(pulse2);
        if (progress > SHOW_HEARTBEAT_PCT) {
            heartbeat2 = true;
        } else {
            Serial.print(" ---> Saw heartbeatB, delaying: ");
            Serial.println(progress);
            nextPulseBTime = millis() + 60000.0/bpmPulseB;
        }
    }

    // If finger's gone, ensure no faked heartbeat
    if (sensor1On < 0) {
        heartbeat1 = false;
        lastPulseATime = 0;
        nextPulseATime = 0;
    } else {
        lastFingerSeenA = millis();
    }
    if (sensor2On < 0) {
        heartbeat2 = false;
        lastPulseBTime = 0;
        nextPulseBTime = 0;
    } else {
        lastFingerSeenB = millis();
    }
    
    // Check for faked/real heartbeat, turn on stem
    if (heartbeat1) {
        lastPulseATime = millis();
        nextPulseATime = lastPulseATime + 60000.0/bpmPulseA;
        if (app1State == STATE_STEM_RISING && petalState != STATE_PETAL_RISING) {
            // If stem is already rising and is about to be cut off, pulse petals
            petalState = STATE_PETAL_RISING;
            beginPetalRising();
        }
        app1State = STATE_STEM_RISING;
        resetStem(pulse1);
        // Use both stems if in single player mode
        if (playerMode == MODE_SINGLE_A) resetStem(pulse2);
    } else if (app1State == STATE_STEM_RISING ||
               (playerMode == MODE_SINGLE_B && app2State == STATE_STEM_RISING)) {
        // Run stem, move to petal when complete
        bool stem1Done = runStemRising(pulse1, playerMode == MODE_SINGLE_B ? pulse2 : pulse1);
        if (stem1Done && app1State == STATE_STEM_RISING) {
            app1State = STATE_RESTING;
            resetStem(pulse1);
            if (playerMode == MODE_SINGLE_A) resetStem(pulse2);
            if (petalState != STATE_PETAL_RISING) {
                petalState = STATE_PETAL_RISING;
                beginPetalRising();
            }
        }
    } 
    
    if (heartbeat2) {
        lastPulseBTime = millis();
        nextPulseBTime = lastPulseBTime + 60000.0/bpmPulseB;
        if (app2State == STATE_STEM_RISING && petalState != STATE_PETAL_RISING) {
            // If stem is already rising and is about to be cut off, pulse petals
            petalState = STATE_PETAL_RISING;
            beginPetalRising();
        }
        app2State = STATE_STEM_RISING;
        resetStem(pulse2);
        if (playerMode == MODE_SINGLE_B) {
            resetStem(pulse1);
        }
    } else if (app2State == STATE_STEM_RISING ||
               (playerMode == MODE_SINGLE_A && app1State == STATE_STEM_RISING)) {
        bool stem2Done = runStemRising(pulse2, playerMode == MODE_SINGLE_A ? pulse1 : pulse2);
        if (stem2Done && app2State == STATE_STEM_RISING) {
            app2State = STATE_RESTING;
            if (playerMode == MODE_SINGLE_B) resetStem(pulse1);
            resetStem(pulse2);
            if (petalState != STATE_PETAL_RISING) {
                petalState = STATE_PETAL_RISING;
                beginPetalRising();
            }
        }
    } 
    
    if (petalState == STATE_PETAL_LANDING) {
        bool ledDone = runPetalResting();
        if (ledDone) {
            petalState = STATE_RESTING;
        }
    } else if (petalState == STATE_PETAL_RISING) {
        bool ledDone = runPetalRising();
        if (ledDone) {
            if (app1State == STATE_PETAL_RISING) app1State = STATE_PETAL_FALLING;
            if (app2State == STATE_PETAL_RISING) app2State = STATE_PETAL_FALLING;
            petalState = STATE_PETAL_FALLING;
            beginPetalFalling();
        }
    } else if (petalState == STATE_PETAL_FALLING) {
        bool ledDone = runPetalFalling();
        if (ledDone) {
            if (app1State == STATE_PETAL_FALLING) app1State = STATE_RESTING;
            if (app2State == STATE_PETAL_FALLING) app2State = STATE_RESTING;
            // Serial.println(" ---> PETAL DONE, RESTING");
            petalState = STATE_AWAKE;
        }
    }

    // Turn off inactive sensors
    determinePlayerMode();
    determineFingerMode(sensor1On, sensor2On);
}

// =================
// = State Machine =
// =================

void determinePlayerMode() {
    unsigned long decay = millis();
    unsigned long fingerDecay;
    decay = decay > (unsigned long)SENSOR_DECAY_MS ? decay - SENSOR_DECAY_MS : 0;
    bool activeA = lastSensorActiveA > decay;
    bool activeB = lastSensorActiveB > decay;
    
    if (activeA && lastFingerSeenA) {
        fingerDecay = millis();
        fingerDecay = fingerDecay > (unsigned long)FINGERLESS_DECAY_MS ? 
                      fingerDecay - FINGERLESS_DECAY_MS : 0;
        activeA = lastFingerSeenA > fingerDecay;
    }
    if (activeB && lastFingerSeenB) {
        fingerDecay = millis();
        fingerDecay = fingerDecay > (unsigned long)FINGERLESS_DECAY_MS ? 
                      fingerDecay - FINGERLESS_DECAY_MS : 0;
            activeB = lastFingerSeenB > fingerDecay;
    }

    if (playerMode == MODE_NONE) {
        if (activeA && activeB) {
            playerMode = MODE_DOUBLE;
        } else if (activeA) {
            playerMode = MODE_SINGLE_A;
        } else if (activeB) {
            playerMode = MODE_SINGLE_B;
        }
    } else if (playerMode == MODE_DOUBLE || 
               playerMode == MODE_SINGLE_A || 
               playerMode == MODE_SINGLE_B) {
        if (activeA && activeB) {
            playerMode = MODE_DOUBLE;
        } else if (activeA && !activeB) {
            playerMode = MODE_SINGLE_A;
        } else if (!activeA && activeB) {
            playerMode = MODE_SINGLE_B;
        } else if (!activeA && !activeB) {
            playerMode = MODE_NONE;
            restState = STATE_RESTING;
        }
    }
}

void determineFingerMode(int sensor1On, int sensor2On) {
    player_mode_t originalFingerMode = fingerMode;
    
    if (sensor1On >= 0 && sensor2On >= 0) {
        fingerMode = MODE_DOUBLE;
    } else if (sensor1On >= 0) {
        fingerMode = MODE_SINGLE_A;
    } else if (sensor2On >= 0) {
        fingerMode = MODE_SINGLE_B;
    } else {
        fingerMode = MODE_NONE;
    }

#ifdef USE_SERIAL
    // Serial.print(" ---> Finger mode: ");
    // Serial.print(fingerMode);
    // Serial.print("/");
    // Serial.println(originalFingerMode);
#endif

    if (fingerMode != originalFingerMode) {
        if (originalFingerMode == MODE_NONE && restState == STATE_STEM_FALLING) {
            // When moving to a finger from rest, split stem.
            beginSplittingStem();
        } else if (fingerMode == MODE_DOUBLE &&
                   (originalFingerMode == MODE_SINGLE_A || 
                    originalFingerMode == MODE_SINGLE_B)) {
            // When moving to double fingers, possibly freezing of stem leds.
            clearStemLeds(&pulseA);
            clearStemLeds(&pulseB);
        }
    }
}

void resetStem(PulsePlug *pulse) {
    clearStemLeds(pulse);

    if (pulse->role == ROLE_PRIMARY) {
        stripACurrentLed = 0;
    } else if (pulse->role == ROLE_SECONDARY) {
        stripBCurrentLed = 0;
    }
}

void clearStemLeds(PulsePlug *pulse) {
    // Reset stem LEDs
    uint8_t pulseWidth = STEMA_PULSE_WIDTH;
    uint8_t bpm = bpmPulseA;
    unsigned long lastBeat = lastPulseATime;
    if (pulse->role == ROLE_SECONDARY) {
        pulseWidth = STEMB_PULSE_WIDTH;
        bpm = bpmPulseB;
        lastBeat = lastPulseBTime;
    }
    Adafruit_NeoPixel strip = Adafruit_NeoPixel(NUMBER_OF_STEM_LEDS, 
                                                pulse->role == ROLE_PRIMARY ? 
                                                stemALedPin : stemBLedPin, 
                                                NEO_GRB + NEO_KHZ800);
    strip.begin();
    for (int i=0; i < NUMBER_OF_STEM_LEDS; i++) {
        strip.setPixelColor(i, 0, 0, 0);
    }
    strip.show();
#ifdef USE_SERIAL
    // Serial.print(F(" ---> Clearing stem #"));
    // Serial.println(pulse->role);
#endif
    unsigned long now = millis();
    unsigned long nextBeat = lastBeat + (int)floor(60000.0/(bpm/STEM_DURATION_PCT));
    unsigned long millisToNextBeat = (now > nextBeat) ? 0 : (nextBeat - now);

    pulse->ease.setDuration(millisToNextBeat);
    pulse->ease.setTotalChangeInPosition(NUMBER_OF_STEM_LEDS + 2*pulseWidth);
}

uint8_t adjustBpm(PulsePlug *pulse) {
    uint8_t bpm = pulse->latestBpm;
    bpm = (uint8_t)floor(smooth((float)bpm, .33, (float)lastBpm));

    if (bpm < 45) bpm = 75;
    if (bpm > 105) bpm = 75;

    lastBpm = bpm;

    return bpm;
}

// ==========
// = States =
// ==========

void runResting() {
#ifdef USE_SERIAL
    // Serial.print(F(" ---> Run resting, current LED: "));
    // Serial.print(stripACurrentLed);
    // Serial.print(F(", rest state: "));
    // Serial.println(restState);
#endif
    if (restState == STATE_RESTING) {
        resetStem(&pulseA);
        resetStem(&pulseB);
#ifdef USE_SERIAL
        Serial.println(" ---> RESETTING Strip current led, due to start resting");
#endif
        stripACurrentLed = NUMBER_OF_STEM_LEDS + REST_PULSE_WIDTH;
        restState = STATE_STEM_FALLING;
        runRestStem();
        beginPetalResting();
    } else if (restState == STATE_STEM_FALLING) {
        runRestStem();
    }
}

void runRestStem() {
    int16_t currentLed = stripACurrentLed - 1;
    if (currentLed < -1*REST_PULSE_WIDTH) {
        currentLed = NUMBER_OF_STEM_LEDS + REST_PULSE_WIDTH;
    }
    stripACurrentLed = currentLed;
    stripBCurrentLed = NUMBER_OF_STEM_LEDS - stripACurrentLed;
    runRestStem(&pulseA, stripACurrentLed);
    runRestStem(&pulseB, stripBCurrentLed);
}

void runRestStem(PulsePlug *pulse, int16_t currentLed) {
    double progress = min(max(0, (float)currentLed/(float)NUMBER_OF_STEM_LEDS), 1.0);
    Adafruit_NeoPixel strip = Adafruit_NeoPixel(NUMBER_OF_STEM_LEDS, 
                                                pulse->role == ROLE_PRIMARY ? 
                                                stemALedPin : stemBLedPin,
                                                NEO_GRB + NEO_KHZ800);
    // Serial.print(" Colors ");
    // Serial.print((int)floor(100*progress));
    // Serial.print("%: ");
    int head = pulse->role == ROLE_PRIMARY ? 0 : (-1*REST_PULSE_WIDTH);
    int tail = pulse->role == ROLE_PRIMARY ? (REST_PULSE_WIDTH) : 1;
                                            
    for (int i=head; i < tail; i++) {
        // Serial.print((int)floor((progress)*255.0/(float)max(abs(i), 1)));
        // Serial.print("/");
        // Serial.print((int)floor(1-progress*255.0/(float)max(abs(i), 1)));
        // Serial.print(" ");
        strip.setPixelColor(currentLed+i, 0, 
                            progress*255.0, 
                            (int)floor(255.0/(float)max(abs(i*3), 1)));
    }
    // Serial.println(currentLed);
    strip.show();
}

// ======================
// = States - Splitting =
// ======================

void beginSplittingStem() {
#ifdef USE_SERIAL
    Serial.print(F(" ---> Run splitting, current LED: "));
    Serial.print(stripACurrentLed);
    Serial.print(F(", rest state: "));
    Serial.println(restState);
#endif
    if (restState == STATE_RESTING || restState == STATE_STEM_FALLING) {
        splitEase.setDuration(STEM_SPLIT_MS);
        splitEase.setTotalChangeInPosition(NUMBER_OF_STEM_LEDS + STEMA_PULSE_WIDTH);
        beginSplitTime = millis();
        splitPivotPoint = stripACurrentLed;
        restState = STATE_STEM_RISING;
    }
}

void runSplittingStem() {
    int progress = (int)ceil(splitEase.easeIn(millis()-beginSplitTime));
    int total = NUMBER_OF_STEM_LEDS + STEMA_PULSE_WIDTH - splitPivotPoint;
#ifdef USE_SERIAL
    Serial.print(" --> Splitting progress: ");
    Serial.print(progress);
    Serial.print(" pivoting: ");
    Serial.println(splitPivotPoint);
#endif
    
    if (splitPivotPoint == 0) {
#ifdef USE_SERIAL
        Serial.println(" ---> Ignoring split");
#endif
        restState = STATE_RESTING;
        return;
    }
    
    if (progress >= total) {
#ifdef USE_SERIAL
        Serial.println(" --> Done splitting!");
#endif
        restState = STATE_RESTING;
        return;
    }
    int16_t currentLed = splitPivotPoint + progress;
    if (currentLed < -1*REST_PULSE_WIDTH) {
        currentLed = NUMBER_OF_STEM_LEDS + REST_PULSE_WIDTH;
    }
    stripACurrentLed = currentLed;
    stripBCurrentLed = NUMBER_OF_STEM_LEDS - stripACurrentLed;
    runSplittingStem(&pulseA, stripACurrentLed);
    runSplittingStem(&pulseB, stripBCurrentLed);
    
    double progressPct = (double)progress / total;
    analogWrite(petalRedPin, 8*progressPct);
    analogWrite(petalGreenPin, 8*progressPct);
    analogWrite(petalBluePin, 255*(1-progressPct));
}
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

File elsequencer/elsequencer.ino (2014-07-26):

// Pulse & Bloom - Ground Lighting
// 2014 - Samuel Clay, samuel@ofbrooklyn.com

// ===========
// = Globals =
// ===========

const uint8_t boardPin = A2;
unsigned long pulseStart = 0;
uint16_t pulseWidth = 1000; // 60 bpm

void clearWires();

// ==========
// = States =
// ==========

typedef enum
{
    STATE_RESTING = 0,
    STATE_PULSE_HIGH = 1,
    STATE_PULSE_LOW = 2
} state_app_t;
state_app_t appState;

// =========
// = Setup =
// =========

void setup() {                
  // The EL channels are on pins 2 through 9
  // Initialize the pins as outputs
  pinMode(2, OUTPUT);  // channel A  
  pinMode(3, OUTPUT);  // channel B   
  pinMode(4, OUTPUT);  // channel C
  pinMode(5, OUTPUT);  // channel D    
  pinMode(6, OUTPUT);  // channel E
  pinMode(7, OUTPUT);  // channel F
  pinMode(8, OUTPUT);  // channel G
  pinMode(9, OUTPUT);  // channel H
  // We also have two status LEDs, pin 10 on the Escudo, 
  // and pin 13 on the Arduino itself
  pinMode(10, OUTPUT);     
  pinMode(13, OUTPUT);    
  
  // The main board drives the pin HIGH for 1/10th of a pulse's bpm
  pinMode(boardPin, INPUT);
  
  appState = STATE_RESTING;
}

// ========
// = Loop =
// ========

void loop() {
    int pulseFound = (millis() % 1000 < 100) || digitalRead(boardPin);

    if (appState == STATE_RESTING) {
        if (pulseFound) {
            pulseStart = millis();
            appState = STATE_PULSE_HIGH;
        }
    }
    
    if (appState == STATE_PULSE_HIGH && !pulseFound) {
        pulseWidth = millis() - pulseStart;
    }
    
    if (appState == STATE_PULSE_HIGH || appState == STATE_PULSE_LOW) {
        clearWires();
        long elapsed = millis() - pulseStart;
        if (elapsed > pulseWidth * 4) {
            appState = STATE_RESTING;
        } else if (elapsed > pulseWidth * 3) {
            digitalWrite(9, LOW);
            digitalWrite(8, LOW);
        } else if (elapsed > pulseWidth * 2) {
            digitalWrite(7, LOW);
            digitalWrite(6, LOW);
        } else if (elapsed > pulseWidth * 1) {
            digitalWrite(5, LOW);
            digitalWrite(4, LOW);
        } else if (elapsed > pulseWidth * 0) {
            digitalWrite(3, LOW);
            digitalWrite(2, LOW);
        }
    }
}

void clearWires() {
    for (int i=2; i <= 9; i++) {
        digitalWrite(i, HIGH);
        i++;
    }
}

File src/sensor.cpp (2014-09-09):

// Based on Paul Badger's work at Modern Device
// http://moderndevice.com/new-products/si1143-based-distance-sensors/

#include <si1143/si1143.h>
#include <si1143/si114_defs.h>
#include "smooth.h"
#include "sensor.h"

// #define USE_SERIAL
// #define PRINT_LED_VALS

const int SAMPLES_TO_AVERAGE = 3;

void setupPulseSensor(PulsePlug *pulse) {
// #ifdef USE_SERIAL
//     if (pulse->isPresent()) {
//         Serial.println("SI1143 Pulse Sensor found OK. Let's roll!");
//     } else {
//         Serial.println("No SI1143 found!");
//     }
// #endif

    pulse->setReg(PulsePlug::HW_KEY, 0x17);  
    
    pulse->setReg(PulsePlug::INT_CFG, 0x03);       // turn on interrupts
    pulse->setReg(PulsePlug::IRQ_ENABLE, 0x10);    // turn on interrupt on PS3
    pulse->setReg(PulsePlug::IRQ_MODE2, 0x01);     // interrupt on ps3 measurement
    pulse->setReg(PulsePlug::MEAS_RATE, 0x84);     // wake up every 10ms
    pulse->setReg(PulsePlug::ALS_RATE, 0x08);      // take measurement every wakeup
    pulse->setReg(PulsePlug::PS_RATE, 0x08);       // take measurement every wakeup
    
    pulse->setReg(PulsePlug::PS_LED21, (SI114_LEDI_022 << 4) | (SI114_LEDI_157));      // LED current for 2 (IR1 - high nibble) & LEDs 1 (red - low nibble) 
    pulse->setReg(PulsePlug::PS_LED3, SI114_LEDI_022);       // LED current for LED 3 (IR2)
/*  debug infor for the led currents */
    Serial.print( "PS_LED21 = ");                                         
    Serial.println(pulse->getReg(PulsePlug::PS_LED21), BIN);                                          
    Serial.print("CHLIST = ");
    Serial.println(pulse->readParam(0x01), BIN);

    pulse->writeParam(PulsePlug::PARAM_CH_LIST, 0x77);         // all measurements on
    // increasing PARAM_PS_ADC_GAIN will increase the LED on time and ADC window
    // you will see increase in brightness of visible LED's, ADC output, & noise 
    // datasheet warns not to go beyond 4 because chip or LEDs may be damaged
    pulse->writeParam(PulsePlug::PARAM_PS_ADC_GAIN, 0x00);
    // You can select which LEDs are energized for each reading.
    // The settings below (in the comments)
    // turn on only the LED that "normally" would be read
    // ie LED1 is pulsed and read first, then LED2 & LED3.
    pulse->writeParam(PulsePlug::PARAM_PSLED12_SELECT, 0x21);  // 21 select LEDs 2 & 1 (red) only                                                               
    pulse->writeParam(PulsePlug::PARAM_PSLED3_SELECT, 0x04);   // 4 = LED 3 only

    // Sensors for reading the three LEDs
    // 0x03: Large IR Photodiode
    // 0x02: Visible Photodiode - cannot be read with LEDs on - just for ambient measurement
    // 0x00: Small IR Photodiode
    pulse->writeParam(PulsePlug::PARAM_PS1_ADCMUX, 0x03);      // PS1 photodiode select 
    pulse->writeParam(PulsePlug::PARAM_PS2_ADCMUX, 0x03);      // PS2 photodiode select 
    pulse->writeParam(PulsePlug::PARAM_PS3_ADCMUX, 0x03);      // PS3 photodiode select  

    pulse->writeParam(PulsePlug::PARAM_PS_ADC_COUNTER, B01110000);    // B01110000 is default                                   
    pulse->setReg(PulsePlug::COMMAND, PulsePlug::PSALS_AUTO_Cmd);     // starts an autonomous read loop
}


int readPulseSensor(PulsePlug *pulse) {
    if (!pulse->valleyTime) pulse->valleyTime = millis();
    if (!pulse->lastValleyTime) pulse->lastValleyTime = millis();
    if (!pulse->peakTime) pulse->peakTime = millis();
    if (!pulse->lastPeakTime) pulse->lastPeakTime = millis();
    
    unsigned long total=0;
    int i=0;
    int IR_signalSize;
    pulse->red = 0;
    pulse->IR1 = 0;
    pulse->IR2 = 0;
    total = 0;
    
    while (i < SAMPLES_TO_AVERAGE){      
        pulse->fetchLedData();
        pulse->red += pulse->ps1;
        pulse->IR1 += pulse->ps2;
        pulse->IR2 += pulse->ps3;
        i++;
    }
    
    pulse->red = pulse->red / i;  // get averages
    pulse->IR1 = pulse->IR1 / i;
    pulse->IR2 = pulse->IR2 / i;
    total =  pulse->IR1 + pulse->IR2 + pulse->red;  // red excluded
    pulse->IRtotal = pulse->IR1 + pulse->IR2;
    
    if (pulse->red == 0 && pulse->IR1 == 0 && pulse->IR2 == 0) {
        delay(500);
#ifdef USE_SERIAL
        Serial.println(" ---> Resetting to fix Pulse Sensor");
#endif
        delay(100);
        resetArduino();
    }

#ifdef PRINT_LED_VALS
    Serial.print(pulse->red);
    Serial.print(F("\t"));
    Serial.print(pulse->IR1);
    Serial.print(F("\t"));
    Serial.print(pulse->IR2);
    Serial.print(F("\t"));
    Serial.println((long)total);   
#endif
    
    if (pulse->red == pulse->IR1 && pulse->IR1 == pulse->IR2) {
        // Missing sensor
        return -1;
    }
    if (pulse->lastTotal < 40000L && total > 40000L) pulse->foundNewFinger = 1;  // found new finger!

    pulse->lastTotal = total;
    
    // if found a new finger prime filters first 20 times through the loop
    if (++(pulse->foundNewFinger) > 25) pulse->foundNewFinger = 25;   // prevent rollover 
    
    if (pulse->foundNewFinger < 20) {
        pulse->IR_baseline = total - 200;   // take a guess at the baseline to prime smooth filter
#ifdef USE_SERIAL
        if (pulse->foundNewFinger == 2) {
            Serial.print(F(" ---> Found new finger - "));
            if (pulse->role == ROLE_PRIMARY) {
                Serial.println(F("primary"));
            } else if (pulse->role == ROLE_SECONDARY) {
                Serial.println(F("secondary"));
            }
        }
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

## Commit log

2014-04-28 Initial commit of prototype heartbeat sensor.
2014-05-04 Smoothing, counting, and calculating an online median for the new sampler.
2014-05-04 Heartbeat indicator now calibrated. Just need to move period around.
2014-05-04 Refactoring to fix sizes. Still firing too often, needs peaking logic worked out.
    [pulse.cpp]
2014-05-06 Much better pulse detection. Now just need to fill in missed pulses.
    [pulse.cpp]
2014-05-06 Much happier with the math. No longer tossing top and bottom 15% of samples, as it was slowing down collection.
    [pulse.cpp]
2014-05-09 Eagle schematic. Needs values, but hookups are all correct.
    [pulse.sch]
2014-05-10 Finished board layout at .8"x1.25". Needs labels, then it's ready to print!
    [pulse.brd, pulse.sch]
2014-05-10 Invoking power/ground on op amp, fixing dimension, drawing polarized lines for tantalum caps, and adjusting labels.
    [pulse.brd, pulse.sch]
2014-05-10 Fixing the last few silkscreen placement lines. Adjusting schematic.
    [pulse.brd, pulse.sch]
2014-05-10 Adding serial port headers.
    [pulse.brd, pulse.sch]
2014-05-30 Rev. A of the board.
    [pulse.brd, pulse.sch]
2014-06-01 Moving pins around.
    [pulse.brd, pulse.sch]
2014-06-10 Rev. 2 of the board, with new headers for el wire, led data, and pwm led.
    [pulse.brd, pulse.sch]
2014-06-10 Fixing glitchy colors on led stem.
    [pulse.cpp]
2014-06-11 Switching from attiny84 to atmega328 for the hardware serial, bigger flash size, additional PWMs, and negligible package size difference.
    [pulse.brd, pulse.sch]
2014-06-19 Switch from crappy IR sensors to SI1143 IC.
    [pulse.brd, pulse.sch]
2014-06-19 Re-orienting and preparing board for layout.
    [pulse.brd, pulse.sch]
2014-06-20 Ripping out all of my code in place of the new Si1143 sensor. Need to add back in strip and petal led logic.
2014-06-21 Revision 4 of the board now connects all 5v, 12v, and 3.3v devices. Revision 1 of the sensor board.
    [pulse.brd, pulse.sch]
2014-06-21 Pulse Sensor board.
    [pulse sensor.brd, pulse sensor.sch]
2014-06-23 Adding extra stem led and three extra petal leds. Needs routing.
    [pulse.brd, pulse.sch]
2014-06-23 Reading new pulse sensor and sending down pulses.
2014-06-23 Fixing pulse sensor bug where it only works after a reset. Why, I don't know, but this works pretty well.
    [pulse.cpp]
2014-06-24 Revision 5 of the board, with 4 x Petals, 2 x Stem.
    [pulse.brd, pulse.sch]
2014-06-24 Adding extra gnd pins for picobucks. probably going to need more picobucks.
    [pulse.brd, pulse.sch]
2014-06-24 Adding second pulse sensor to board and code. Need to write code to handle second pulse sensor and second stem.
    [pulse.brd, pulse.sch]
2014-06-25 Abstracted out pulse sensors so that multiple pulse sensors can control multiple strips. Crashes when second pulse sensor is used.
    [pulse.cpp]
2014-06-25 Fixing memory issues by moving neopixel strip to local functions to reclaim RAM.
    [pulse.cpp]
2014-07-08 Adding a barrel jack and proper buck converter connectors.
    [pulse.brd, pulse.sch]
2014-07-09 Refactoring pulse sensor. Fixing issues around having one or the other pulse sensor turned on.
    [pulse.cpp, sensor.cpp]
2014-07-15 Resting state now using cylons and uses both stem leds.
2014-07-16 Fixing bug where a pulse before the pulse decay time would not clear the resting state.
    [pulse.cpp]
2014-07-16 Perfecting the petal fade and fixing issues when using two sensors and having the petal bounce.
    [pulse.cpp]
2014-07-16 Fixing lingering brightness issues.
    [pulse.cpp]
2014-07-16 The big one. Heartbeats are now faked with real heartbeats quickly pushing faked data into correct data. Looks great and has few false positives.
    [pulse.cpp, sensor.cpp]
2014-07-17 Revision 2 of the pulse sensor. Upgrading to tantalum cap, switching the two caps, and using the correct resistor value. Also switching to temrinal connectors on bottom of board.
    [pulse sensor.brd, pulse sensor.sch]
2014-07-23 Fixing initial programming with correct optimization flag.
    [pulse.cpp]
2014-07-23 Stubbing in ground lights.
2014-07-26 Fixing petal led brightness reset glitch when multiple pulses are running.
    [elsequencer.ino, pulse.cpp, sensor.cpp]
2014-08-01 Fixing pulse sensor to use new leds.
    [pulse.cpp, sensor.cpp]
2014-08-01 Adding sketchup model for cowl.
    [Pulse Sensor Cowl.skp, Pulse Sensor Cowl~.skp]
2014-08-02 Instant finger detection. Works when a finger is new and when a finger leaves.
2014-08-02 A beautiful effect. When a new finger touches the sensor, the resting animation quickly winds backwards, turning into heartbeats.
2014-08-04 Adding cowl OBJ file for printing.
    [Pulse Sensor Cowl.obj]
2014-08-11 Fixing bug where the rest split state would run when a finger was lifted during stem rise.
    [pulse.cpp]
2014-08-11 Improved heart beat pacing. Also fixing second premature splitting issue.
    [pulse.cpp]
2014-08-11 When moving to double fingers, possibly freezing of stem leds.
2014-08-13 Adding petal led delay to make the petals stay bright for a tenth of a second longer.
2014-08-13 Adding wiring diagram in OmniGraffle.
2014-08-14 Setting off petals when stem gets interrupted.
2014-08-14 Adding petal landing and landed state.
2014-08-15 Fixing obnoxious petal blink when petal is told to rise while already rising.
    [pulse.cpp]
2014-08-23 Handling missing pulse sensor.
    [sensor.cpp]
2014-09-05 Custom boards.
2014-09-05 Sensors and LEDs.
2014-09-05 Blogged the battery section.
2014-09-09 Adding modern device header.
2014-12-20 commiting changes by sam during burning man 2014
    [pulse.cpp]
2016-08-05 Petal LEDs pdf.

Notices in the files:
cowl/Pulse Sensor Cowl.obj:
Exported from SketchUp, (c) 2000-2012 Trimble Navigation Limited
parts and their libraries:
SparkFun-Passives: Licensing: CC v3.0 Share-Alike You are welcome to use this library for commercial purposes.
